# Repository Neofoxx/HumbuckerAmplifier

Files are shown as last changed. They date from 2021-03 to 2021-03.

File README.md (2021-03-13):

# HumbuckerAmplifier
An amplifier for humbucking pickups (like other popular brands). Just a bit cheaper and more versatile.

#### Render
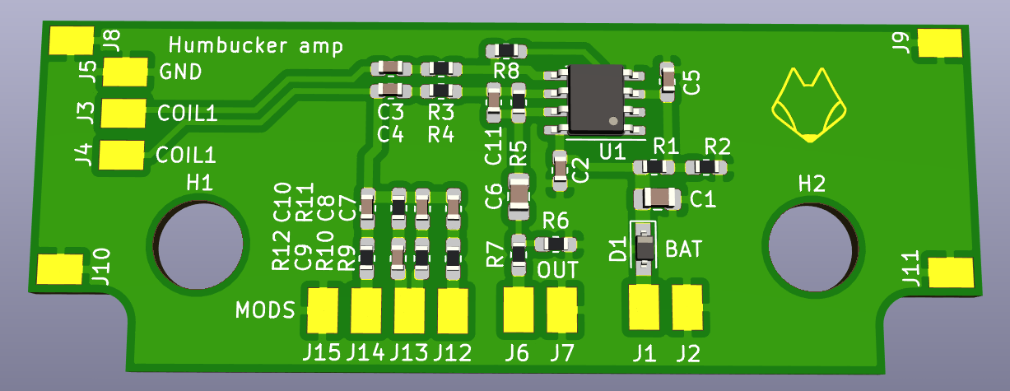
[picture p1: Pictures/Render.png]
Render


#### Mounting
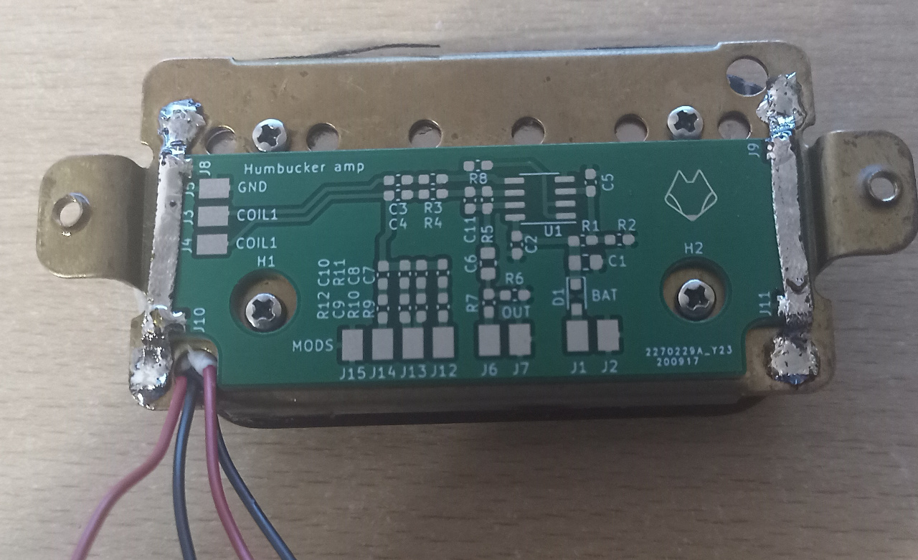
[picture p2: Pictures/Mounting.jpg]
Mounting


#### Schematic
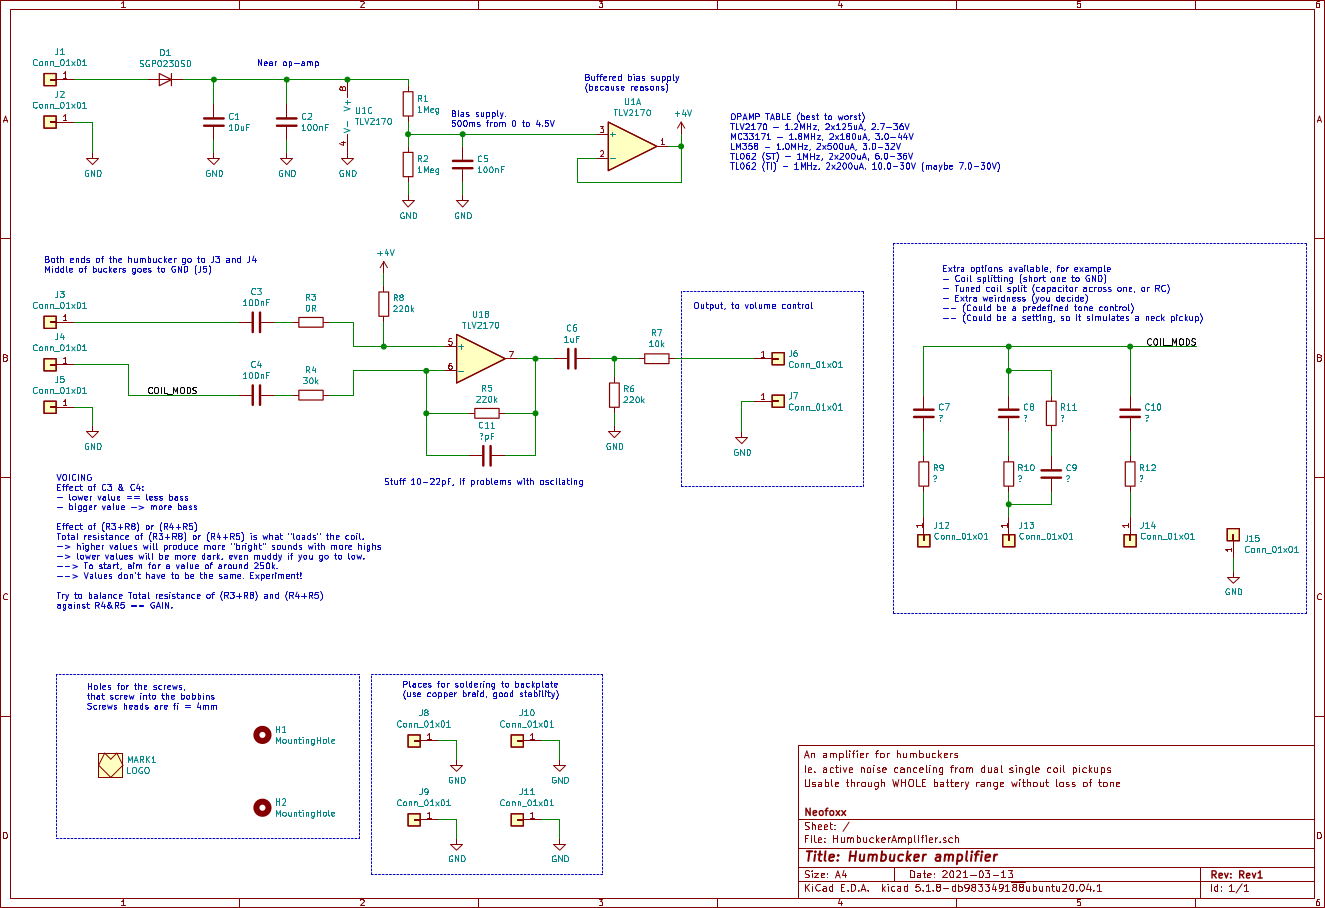
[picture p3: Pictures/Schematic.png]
Schematic


## Description
This is an amplifier for humbucking pickups. It takes two coils, with one side of each connected to GND, and the other to the input. Take care to connect properly, otherwise you will get a noise amplifier :) (in-phase sound will cancel, and out-of-phase noise will amplify).

**Note, you need either a 4-wire pickup, or some soldering skills. You cannot use a series humbucker, or a parallel humbucker**

The curcuit uses a dual opamp, so you can play around with voicing without fear of power supply modulation distortion etc.

A TLV2170 will give great results, as will an MC33171. Other opamps like TL072 or TL062 will be *OK*, but in that case I suggest upping the voltage to 18V. Consult the schematic.

## Features

- Gain can be as high as you want, but be warned that amps usually have limited input headroom, so beyond some point "making it louder" will have a negative effect.

- The circuit is usable throught the batteries entire range. Works just find with power-switching on the output jack (TRS jack, short R (Bat-) and S (GND)).

- Since this is a one-sided board, it can be easily made at home.

- **REVERSE POLARITY PROTECTION**

- The circuit board should fit comfortably under a humbucker, but you can relocate it if you want to.

- Use desoldering braid to mount the PCB to the board (see pictures)

## Voicing
The circuit is quite versatile, as there are multiple positions prepared for mods & voicing.

### Basic voicing
Voicing can be done in these ways:

- Capacitors C3 and C4 define how lows are passed through. Small value == less lows, more highs. There reverse is true for Big values.

- Value of (R3+R8) and (R4+R5) define the "loading" of each coil. This defines the resonance peak. Think how a single coil "needs" 250k pots, and humbuckers need "500k" pots. Higher values will shift the resonance higher, and can produce "shrill" or ice pick-y sounds. Lower values will shift the resonance down, and make a more mellow, or muddy tone.

- The value of (R3+R8) and (R4+R5) doesn't have to be the same. C3 and C4 as well. Experiment with values, trust your ears.

- Gain is defined with R4 and R5. Gain = 1 + (R5/R2). Well, it also depends on (R3 and R8), but in practice you can just go with the simple forumla.

- C11 is there to help you if you go crazy with gain. A few pF is all you need usually.

### Advanced voicing
There are some footprints prepared for extra voicing. You can then connect a switch/push-pull pot/? between those footprints and GND, to spice things up.
Some examples /w speculation:
- C7 = 0ohm jumper, R9 = 220k. This will shift the resonance of one coil down. This can help spread the gain on higher frequencies more evenly.
- C10 = 2.2nF, R12 = 0ohm, This is like a selective filter. Should give you a bit of a bass boost.
- C8, C9, R10 and R11 are prepared just so you can do some funky stuff. Can also place something like a diode there, or inductors, etc. Dunno, go nuts.
- C7 = 0ohm, R9 = 0ohm. This will short a coil, and effectively give you a single coil with **GAIN**. But this also means no noise canceling, so YMMV.

#### But what about audio grade capacitors??
No amount of NOS PIO capacitors, carbon resistors and magic smoke in the form of vintage opamps will improve your sound as much as practice will.

## Files
* The Gerber files are in the HW/Gerbers directory
* The BOM is in the HW/ibom directory
* The schematic is here in the root directory

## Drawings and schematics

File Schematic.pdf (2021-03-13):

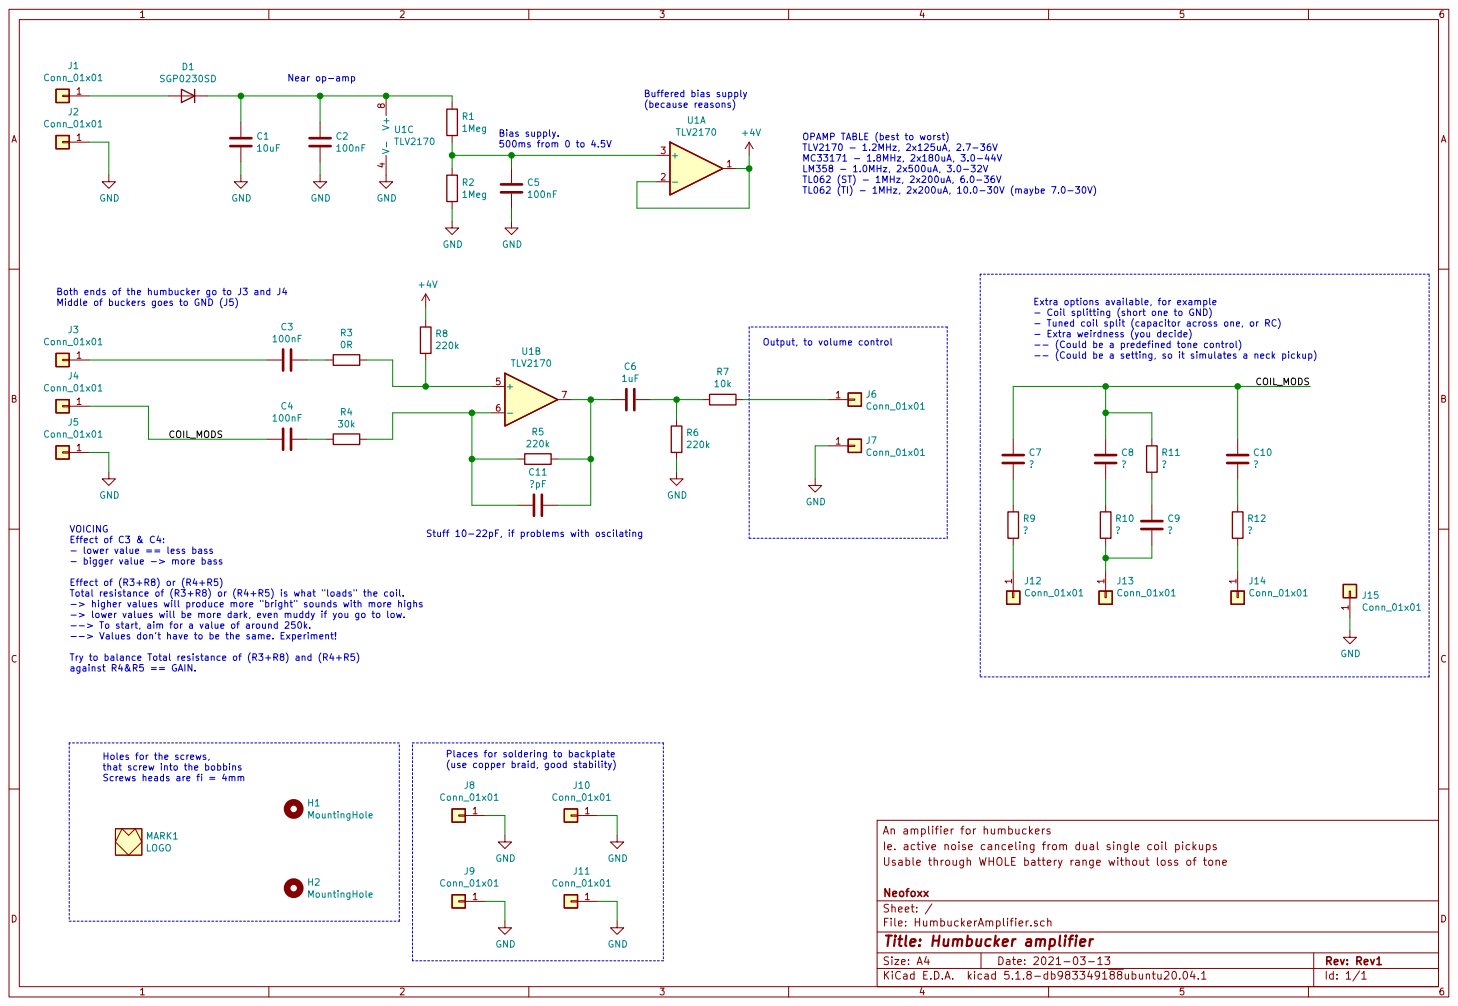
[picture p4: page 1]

Bias supply. 500ms from 0 to 4.5V

OPAMP TABLE (best to worst) TLV2170 - 1.2MHz, 2x125uA, 2.7-36V MC33171 - 1.8MHz, 2x180uA, 3.0-44V

Both ends of the humbucker go to J3 and J4
Middle of buckers goes to GND (J5)

Extra options available, for example
- Coil splitting (short one to GND)
- Tuned coil split (capacitor across one, or RC)
- Extra weirdness (you decide)
-- (Could be a predefined tone control)
-- (Could be a setting, so it simulates a neck pickup)

Output, to volume control

An amplifier for humbuckers R4

VOICING
Stuff 10-22pF, if problems with oscilating Holes for the screws,
Effect of C3 & C4: - lower value == less bass

- bigger value -> more bass

Effect of (R3+R8) or (R4+R5)
Total resistance of (R3+R8) or (R4+R5) is what "loads" the coil.
-> higher values will produce more "bright" sounds with more highs
-> lower values will be more dark, even muddy if you go to low. --> To start, aim for a value of around 250k. --> Values don't have to be the same. Experiment!

Try to balance Total resistance of (R3+R8) and (R4+R5)
against R4&R5 == GAIN.

Places for soldering to backplate
(use copper braid, good stability)
J8 Conn_01x01GND

that screw into the bobbins Screws heads are fi = 4mm

Ie. active noise canceling from dual single coil pickups
File: HumbuckerAmplifier.sch Sheet: / Neofoxx Usable through WHOLE battery range without loss of tone

Id: 1/1 Title: Humbucker amplifier

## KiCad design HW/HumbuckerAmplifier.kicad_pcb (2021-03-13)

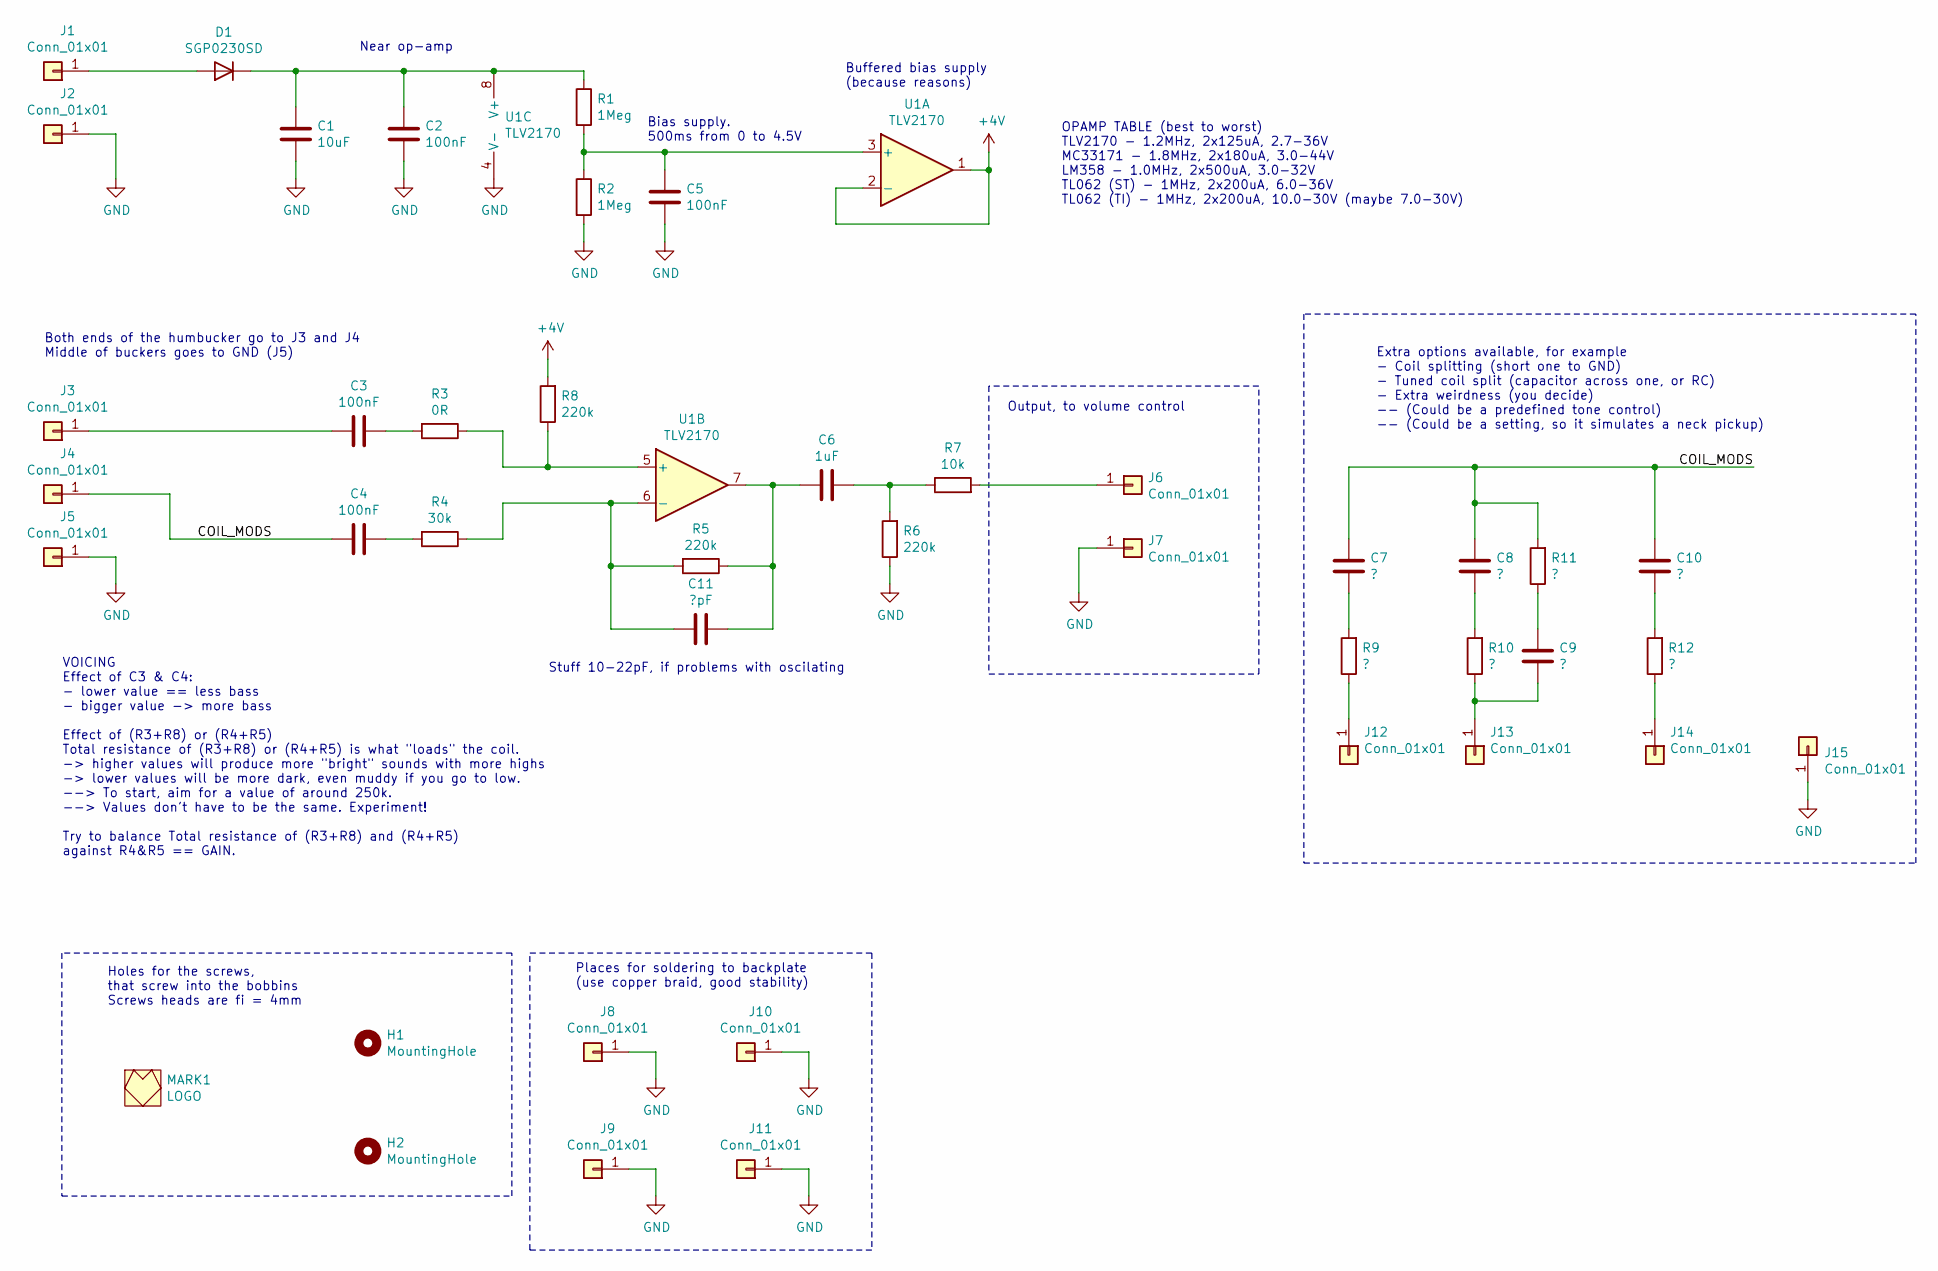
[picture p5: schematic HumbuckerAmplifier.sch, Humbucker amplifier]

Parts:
C1: 10uF; C_0805_2012Metric_Pad1.15x1.40mm_HandSolder
C2, C3, C4, C5: 100nF; C_0603_1608Metric_Pad1.05x0.95mm_HandSolder
C6: 1uF; C_0805_2012Metric_Pad1.15x1.40mm_HandSolder
C7, C8, C9, C10: ?; C_0603_1608Metric_Pad1.05x0.95mm_HandSolder
C11: ?pF; C_0603_1608Metric_Pad1.05x0.95mm_HandSolder
D1: SGP0230SD; D_SOD-323_HandSoldering
H1, H2: MountingHole; MountingHole_6mm
J1, J2, J3, J4, J5, J6, J7, J8, J9, J10, J11, J12, J13, J14, J15: Conn_01x01; SolderPad_2x3mm
MARK1: LOGO; FOX_LOGO_MASK
R1, R2: 1Meg; R_0603_1608Metric_Pad1.05x0.95mm_HandSolder
R3: 0R; R_0603_1608Metric_Pad1.05x0.95mm_HandSolder
R4: 30k; R_0603_1608Metric_Pad1.05x0.95mm_HandSolder
R5, R6, R8: 220k; R_0603_1608Metric_Pad1.05x0.95mm_HandSolder
R7: 10k; R_0603_1608Metric_Pad1.05x0.95mm_HandSolder
R9, R10, R11, R12: ?; R_0603_1608Metric_Pad1.05x0.95mm_HandSolder
U1: TLV2170; SOIC-8_3.9x4.9mm_P1.27mm

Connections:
+4V: R8.2, U1.1, U1.2 (-)
/COIL_MODS: C4.2, C7.2, C8.2, C10.2, J4.1, R11.2
GND: C1.2, C2.2, C5.2, J2.1, J5.1, J7.1, J8.1, J9.1, J10.1, J11.1, J15.1, R2.2, R6.1, U1.4 (V-)
unnamed: C1.1, C2.1, D1.1 (K), R1.1, U1.8 (V+)
unnamed: C3.1, R3.2
unnamed: C3.2, J3.1
unnamed: C4.1, R4.2
unnamed: C5.1, R1.2, R2.1, U1.3 (+)
unnamed: C6.1, R6.2, R7.1
unnamed: C7.1, R9.2
unnamed: C8.1, R10.2
unnamed: C9.1, J13.1, R10.1
unnamed: C9.2, R11.1
unnamed: C10.1, R12.2
unnamed: C6.2, C11.1, R5.1, U1.7
unnamed: C11.2, R4.1, R5.2, U1.6 (-)
unnamed: D1.2 (A), J1.1
unnamed: J6.1, R7.2
unnamed: J12.1, R9.1
unnamed: J14.1, R12.1
unnamed: R3.1, R8.1, U1.5 (+)

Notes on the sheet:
Holes for the screws, that screw into the bobbins Screws heads are fi = 4mm
Bias supply. 500ms from 0 to 4.5V
Near op-amp
Buffered bias supply (because reasons)
Both ends of the humbucker go to J3 and J4 Middle of buckers goes to GND (J5)
Places for soldering to backplate (use copper braid, good stability)
Extra options available, for example - Coil splitting (short one to GND) - Tuned coil split (capacitor across one, or RC) - Extra weirdness (you decide) -- (Could be a predefined tone control) -- (Could be a setting, so it simulates a neck pickup)
OPAMP TABLE (best to worst) TLV2170 - 1.2MHz, 2x125uA, 2.7-36V MC33171 - 1.8MHz, 2x180uA, 3.0-44V LM358 - 1.0MHz, 2x500uA, 3.0-32V TL062 (ST) - 1MHz, 2x200uA, 6.0-36V TL062 (TI) - 1MHz, 2x200uA, 10.0-30V (maybe 7.0-30V)
Stuff 10-22pF, if problems with oscilating
Output, to volume control
VOICING Effect of C3 & C4: - lower value == less bass - bigger value -> more bass Effect of (R3+R8) or (R4+R5) Total resistance of (R3+R8) or (R4+R5) is what "loads" the coil. -> higher values will produce more "bright" sounds with more highs -> lower values will be more dark, even muddy if you go 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

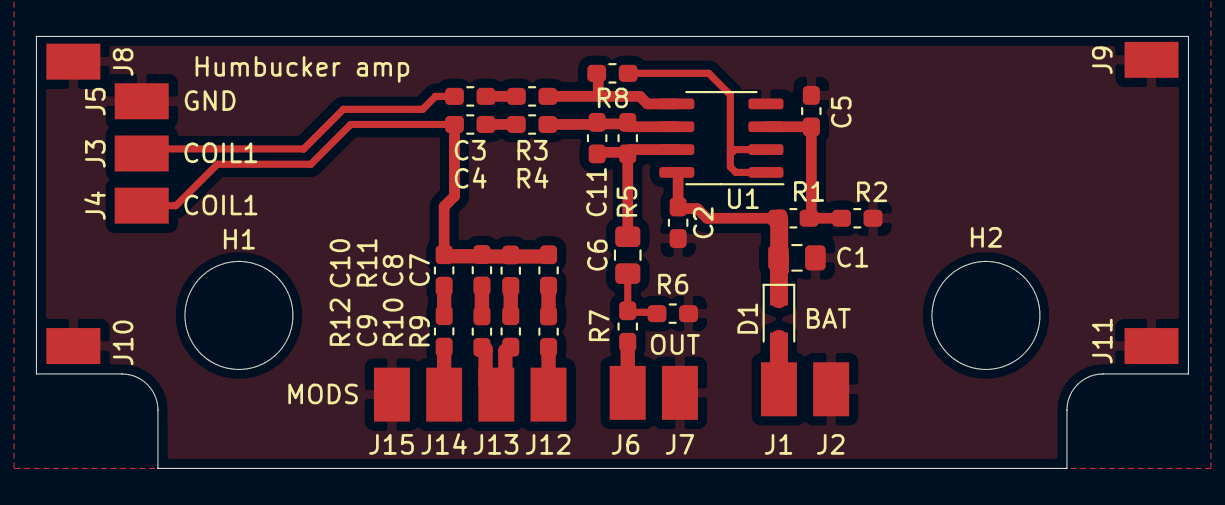
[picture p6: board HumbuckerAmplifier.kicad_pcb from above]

Board: 2 copper layers, 64.0 x 24.0 mm, 43 parts (0 on the bottom side), 21 nets.
